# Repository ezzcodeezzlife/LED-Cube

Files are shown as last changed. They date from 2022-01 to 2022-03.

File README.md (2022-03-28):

# LED-Cube

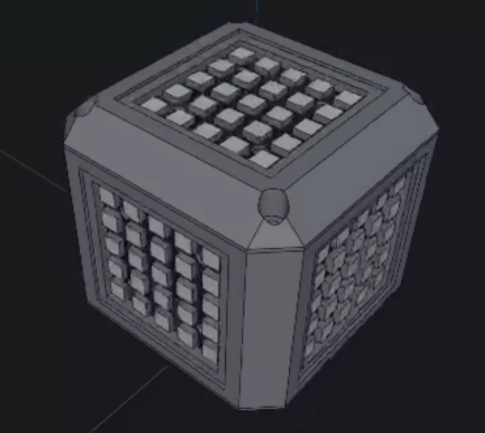
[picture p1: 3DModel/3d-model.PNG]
3d Cube


## Idee

Für unser Bachelorprojekt haben wir uns im Team überlegt, einen Würfel zu bauen, der auf jeder Seite LED Panels verbaut hat und somit Zahlen anzeigen kann. Beim Würfeln soll eine Lichtanimation und die gewürfelte Zahl aufleuchten. Die Zahl wird an einen Webserver übertragen und auf einer Website angezeigt. Mit zwei Würfeln kann man online mit seinen Freunden spielen.
Den Würfel möchten wir mit einem 3D-Druck selbst herstellen, der Controller befindet sich in dem Würfel und steuert die LEDs an.

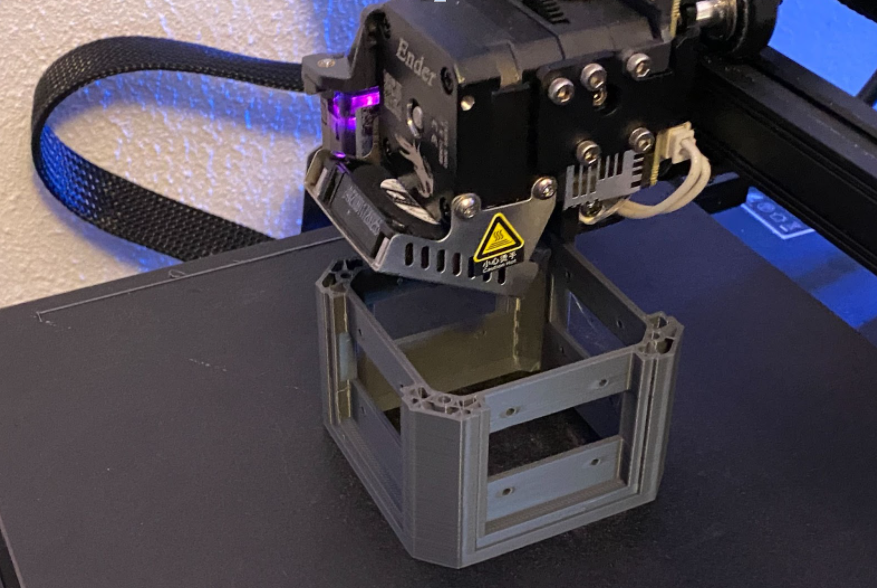
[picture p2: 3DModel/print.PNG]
3d Cube print


## Schaltplan
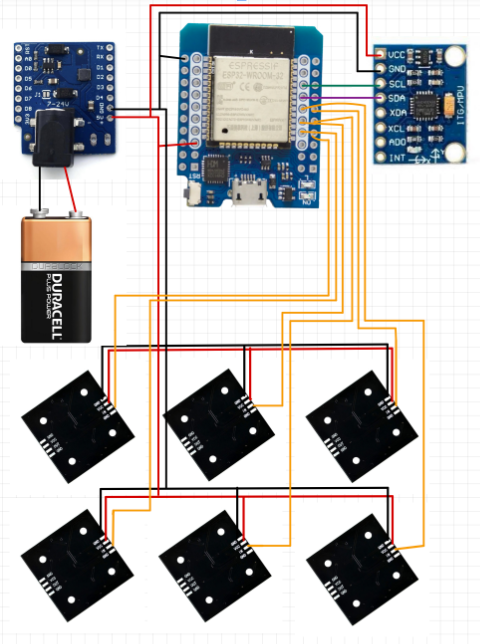
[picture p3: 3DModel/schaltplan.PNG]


## Dokumentation
[Ausarbeitung](https://github.com/ezzcodeezzlife/LED-Cube/blob/main/Dokumentation/Ausarbeitung_Projektvorstellung%20–%20LEDCube.pdf)

[Präsentation](https://github.com/ezzcodeezzlife/LED-Cube/blob/main/Dokumentation/Präsentation_Projektvorstellung%20–%20LEDCube.pdf)

[Video](https://github.com/ezzcodeezzlife/LED-Cube/blob/main/Dokumentation/LEDCube.mp4)

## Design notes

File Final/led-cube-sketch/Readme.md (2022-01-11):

# Arduino IDE konfigurieren

_Boardverwalter hinzufügen:_
* URL: https://dl.espressif.com/dl/package_esp32_index.json
* Paket: ESP32
* Board: WEMOS D1 MINI ESP32

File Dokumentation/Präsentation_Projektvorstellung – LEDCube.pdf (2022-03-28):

# LEDCube

# Bachelorprojekt DM

Marvin Spiegel, Ben Saloch, Fabian Stehle, Lara Ihlau

# Inhalte

- Idee
- Planung
- Durchführung
- Probleme
- Vorführung
- Ausblick

# IDEE

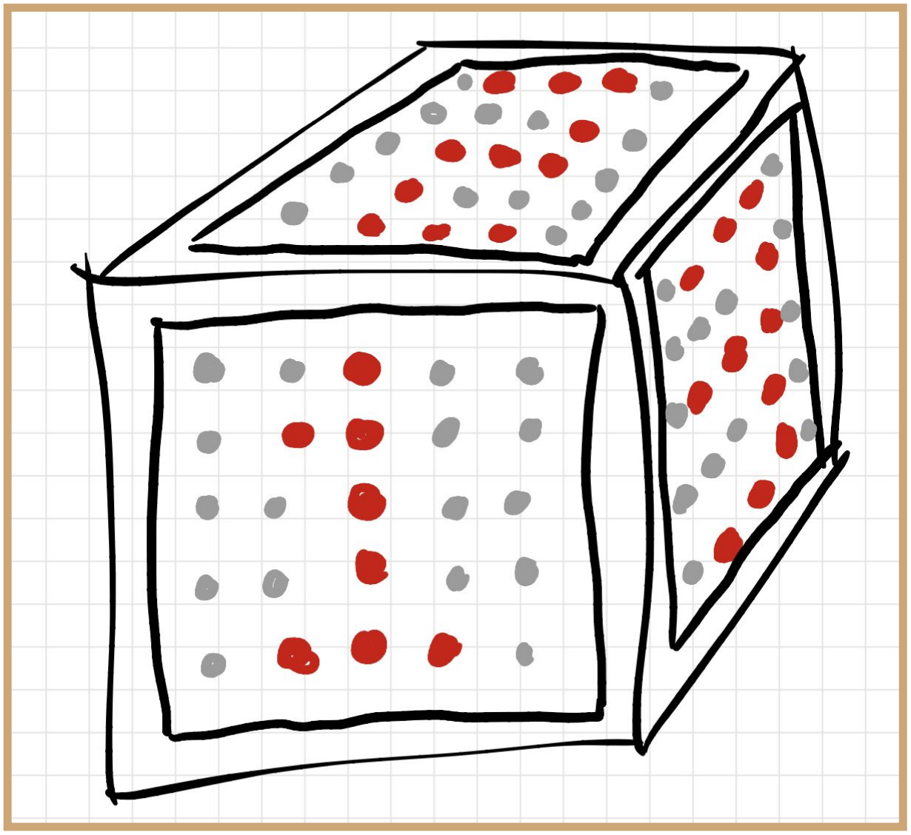
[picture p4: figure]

- Würfel mit Leuchten für Zahlen
- Anzeige über LED-Panels
- Sensor misst Lage im Raum
- Controller sendet an Webserver
- Anzeige einer Animation

# IDEE

# PLANUNG

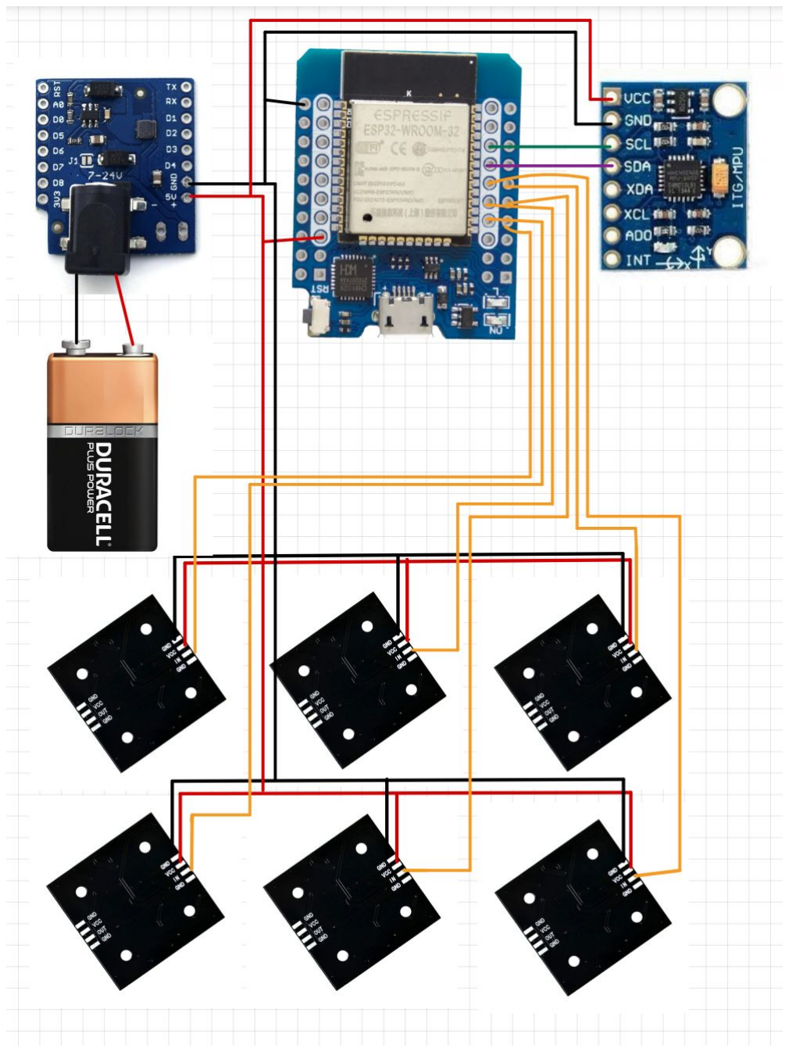
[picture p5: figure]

- zunächst andere Technik geplant

# PLANUNG

Controller | 1x Wemos D1 Mini ESP32
Input | 1x MPU 6050
Output | 6x WS2812 LED Matrix 5×5
Power | 1x 9V-Block-Batterie 1x battery-shield

Komponenten

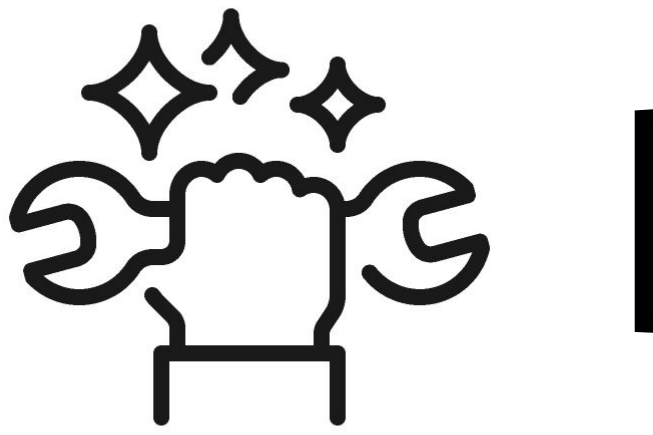
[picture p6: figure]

# DURCHFÜHRUNG

# DURCHFÜHRUNG 1/2

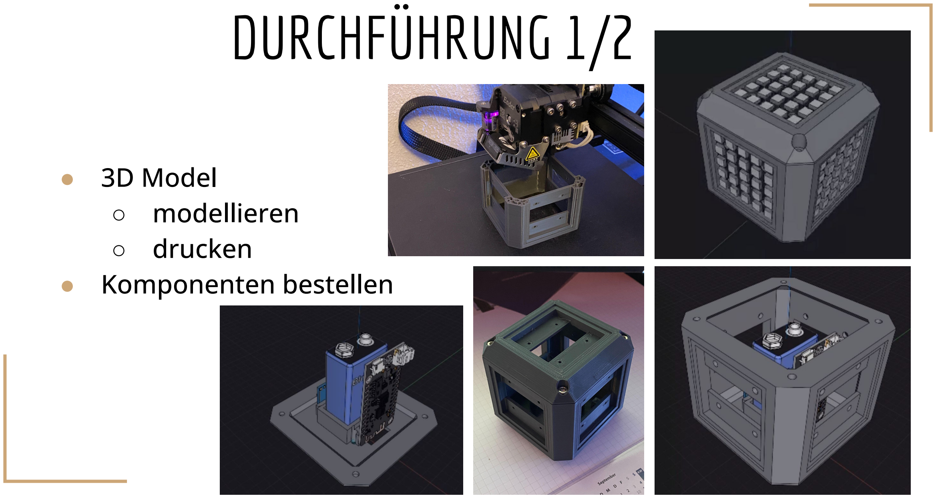
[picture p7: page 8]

- 3D Model
- modellieren
- drucken
- Komponenten bestellen

# DURCHFÜHRUNG 2/2

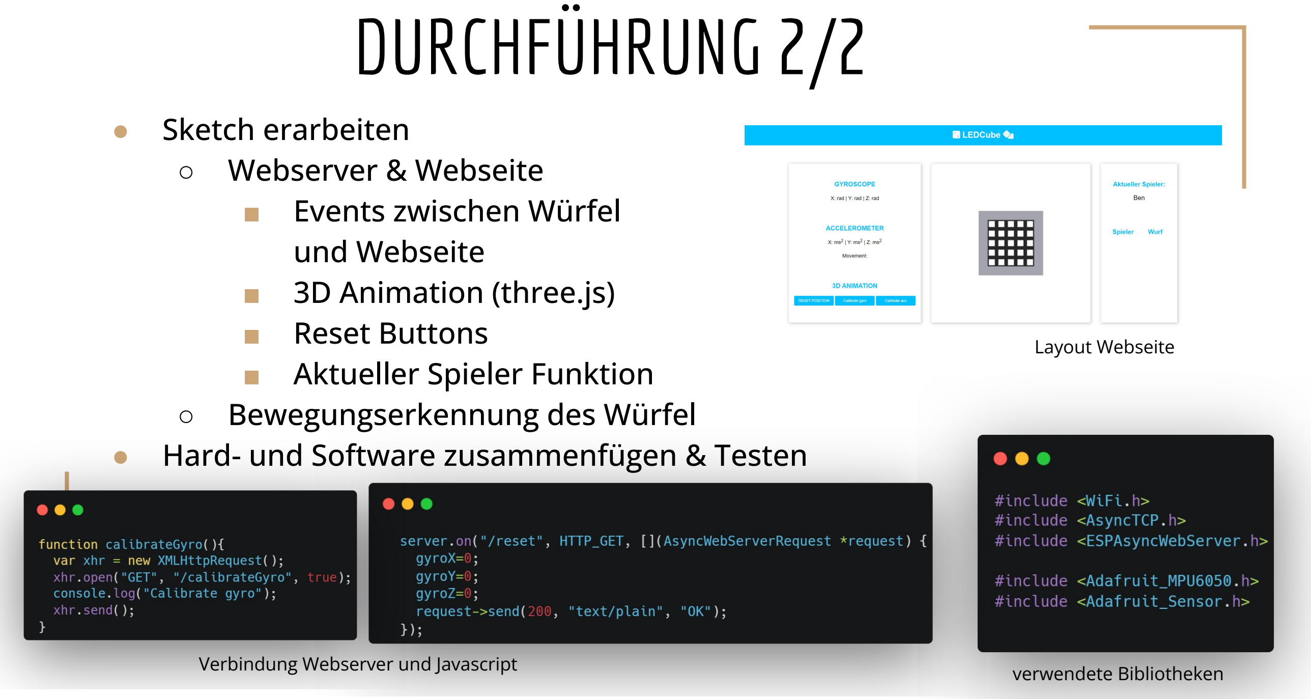
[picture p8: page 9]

- Sketch erarbeiten
- Webserver & Webseite
■ Events zwischen Würfel
und Webseite
■ 3D Animation (three.js)
■ Reset Buttons
■ Aktueller Spieler Funktion
- Bewegungserkennung des Würfel
- Hard- und Software zusammenfügen & Testen
Verbindung Webserver und Javascript | verwendete Bibliotheken

Layout Webseite

# AUFBAU

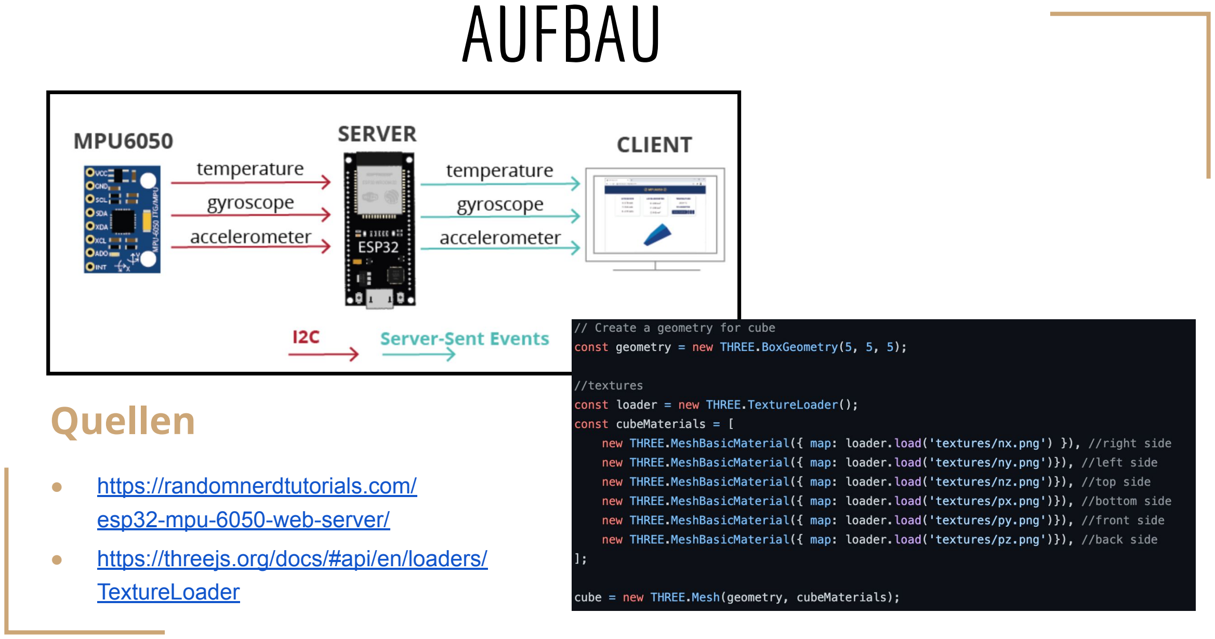
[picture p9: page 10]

Quellen

- https://randomnerdtutorials.com/esp32-mpu-6050-web-server/ (https://randomnerdtutorials.com/esp32-mpu-6050-web-server/)
- https://threejs.org/docs/#api/en/loaders/TextureLoader (https://threejs.org/docs/#api/en/loaders/TextureLoader)

# PROBLEME

# Probleme

- LEDs flackern
- LEDs verbrauchen zu viel Strom der 9V-Block-Batterie
- Threejs Würfel Texturen

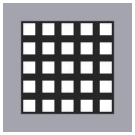
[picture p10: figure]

- Sketch ließ sich nicht hochladen
- keine Fehlermeldungen & Output

# VORFÜHRUNG

# AUSBLICK

# Vielen Dank für Ihre Aufmerksamkeit

weitere Fragen?

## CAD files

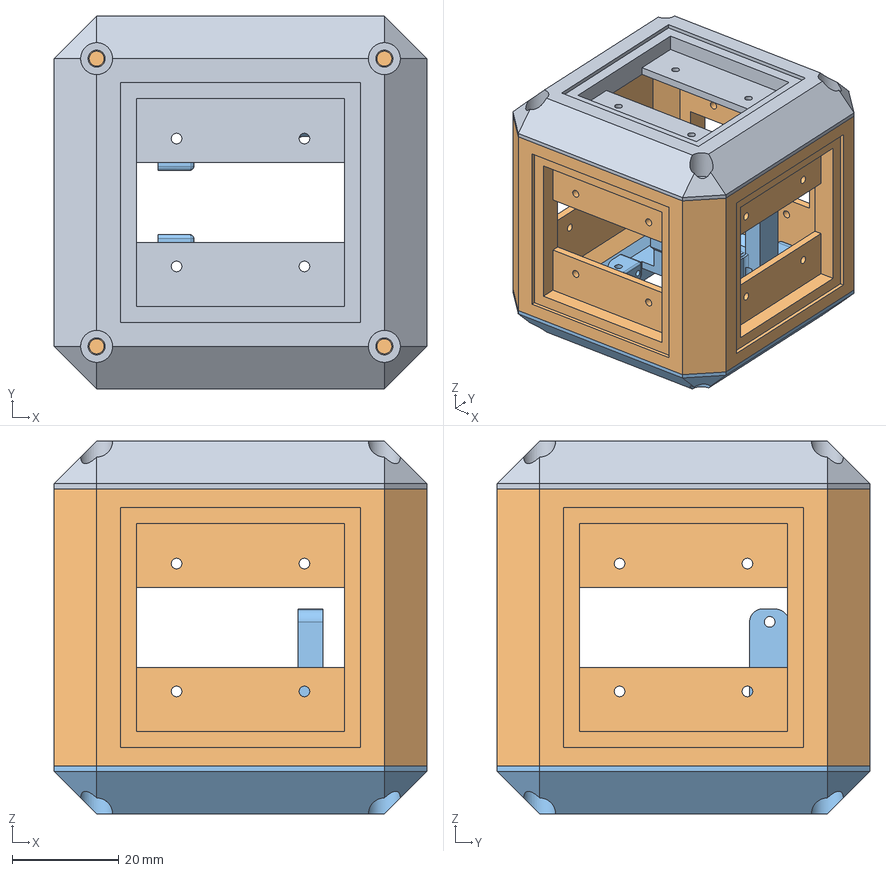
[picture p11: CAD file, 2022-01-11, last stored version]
3DModel/LEDCube.step
70.0 x 70.0 x 70.0 mm
top
middle
bottom

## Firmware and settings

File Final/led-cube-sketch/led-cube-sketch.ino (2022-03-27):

#include <Arduino.h>
#include <WiFi.h>
#include <AsyncTCP.h>
#include <ESPAsyncWebServer.h>
#include <Adafruit_MPU6050.h>
#include <Adafruit_Sensor.h>
#include <Arduino_JSON.h>
#include <Adafruit_GFX.h>
#include <Adafruit_NeoMatrix.h>
#include <Adafruit_NeoPixel.h>
#include "SPIFFS.h"

// Replace with your network credentials
const char* ssid = "LEDCube";
const char* password = "ledcube!";

// PINS
const int PIN1 = 18;
const int PIN2 = 19;
const int PIN3 = 23;
const int PIN4 = 33;
const int PIN5 = 5;
const int PIN6 = 26;
const int NUMPIXELS = 25;

// Create AsyncWebServer object on port 80
AsyncWebServer server(80);

// Create an Event Source on /events
AsyncEventSource events("/events");

// Json Variable to Hold Sensor Readings
JSONVar readings;

// Timer variables
unsigned long lastTime = 0;  
unsigned long lastTimeAcc = 0;
unsigned long movingStartTime = 0;
unsigned long movingStopTime = 0;
unsigned long gyroDelay = 10;
unsigned long accelerometerDelay = 200;
unsigned long movingStartDelay = 1000;
unsigned long movingStopDelay = 3000;

// MPU6050 object
Adafruit_MPU6050 mpu;
sensors_event_t a, g, temp;

/// Readings
float gyroX, gyroY, gyroZ;
float accX, accY, accZ;

// Gyroscope sensor deviation
float gyroXerror = -0.070218;
float gyroYerror = -0.011311;
float gyroZerror = -0.011546;

// Accelerometer deviation
float accXtarget = 0.0;
float accYtarget = 0.0;
float accZtarget = 9.81;
float accXerror = 0.273466;
float accYerror = 0.023643;
float accZerror = -1.416153;

// Calibration temp sums
float gyroXsum = 0;
float gyroYsum = 0;
float gyroZsum = 0;
float accXsum = 0;
float accYsum = 0;
float accZsum = 0;

// Movement detection states
boolean isMoving = false;
boolean wasMoving = false;

// LED panel control
Adafruit_NeoMatrix matrix1 = Adafruit_NeoMatrix(5, 5, PIN1,
  NEO_MATRIX_BOTTOM  + NEO_MATRIX_RIGHT +  //NEO_MATRIX_TOP     + NEO_MATRIX_LEFT +
  NEO_MATRIX_COLUMNS + NEO_MATRIX_ZIGZAG,
  NEO_GRB            + NEO_KHZ800);

Adafruit_NeoMatrix matrix2 = Adafruit_NeoMatrix(5, 5, PIN2,
  NEO_MATRIX_BOTTOM  + NEO_MATRIX_RIGHT +  //NEO_MATRIX_TOP     + NEO_MATRIX_LEFT +
  NEO_MATRIX_COLUMNS + NEO_MATRIX_ZIGZAG,
  NEO_GRB            + NEO_KHZ800);

Adafruit_NeoMatrix matrix3 = Adafruit_NeoMatrix(5, 5, PIN3,
  NEO_MATRIX_BOTTOM  + NEO_MATRIX_RIGHT +  //NEO_MATRIX_TOP     + NEO_MATRIX_LEFT +
  NEO_MATRIX_COLUMNS + NEO_MATRIX_ZIGZAG,
  NEO_GRB            + NEO_KHZ800);

Adafruit_NeoMatrix matrix4 = Adafruit_NeoMatrix(5, 5, PIN4,
  NEO_MATRIX_BOTTOM  + NEO_MATRIX_RIGHT +  //NEO_MATRIX_TOP     + NEO_MATRIX_LEFT +
  NEO_MATRIX_COLUMNS + NEO_MATRIX_ZIGZAG,
  NEO_GRB            + NEO_KHZ800);

Adafruit_NeoMatrix matrix5 = Adafruit_NeoMatrix(5, 5, PIN5,
  NEO_MATRIX_BOTTOM  + NEO_MATRIX_RIGHT +  //NEO_MATRIX_TOP     + NEO_MATRIX_LEFT +
  NEO_MATRIX_COLUMNS + NEO_MATRIX_ZIGZAG,
  NEO_GRB            + NEO_KHZ800);

Adafruit_NeoMatrix matrix6 = Adafruit_NeoMatrix(5, 5, PIN6,
  NEO_MATRIX_BOTTOM  + NEO_MATRIX_RIGHT +  //NEO_MATRIX_TOP     + NEO_MATRIX_LEFT +
  NEO_MATRIX_COLUMNS + NEO_MATRIX_ZIGZAG,
  NEO_GRB            + NEO_KHZ800);

struct RGB {
  byte r;
  byte g;
  byte b;
};

RGB w = { 255, 255, 255 }; //white
RGB r = { 255,   0,   0 }; //red
RGB t = { 0,   255,   0 }; //turkis
RGB b = { 0,     0, 255 }; //blue
RGB y = { 255, 255,   0 }; //yellow
RGB m = { 255,   0, 255 }; //magenta
RGB c = { 0,   255, 150 }; //cyan
RGB o = { 0,     0,   0 }; //off

RGB n1[5][5] = {
  {o, o, o, o, o},
  {o, o, o, o, o},
  {o, o, t, o, o},
  {o, o, o, o, o},
  {o, o, o, o, o},
};

RGB n2[5][5] = {
  {o, o, o, o, o},
  {o, y, o, o, o},
  {o, o, o, o, o},
  {o, o, o, y, o},
  {o, o, o, o, o},
};

RGB n3[5][5] = {
  {c, o, o, o, o},
  {o, o, o, o, o},
  {o, o, c, o, o},
  {o, o, o, o, o},
  {o, o, o, o, c},
};

RGB n4[5][5] = {
  {o, o, o, o, o},
  {o, b, o, b, o},
  {o, o, o, o, o},
  {o, b, o, b, o},
  {o, o, o, o, o},
};

RGB n5[5][5] = {
  {m, o, o, o, m},
  {o, o, o, o, o},
  {o, o, m, o, o},
  {o, o, o, o, o},
  {m, o, o, o, m},
};

RGB n6[5][5] = {
  {r, o, o, o, r},
  {o, o, o, o, o},
  {r, o, o, o, r},
  {o, o, o, o, o},
  {r, o, o, o, r},
};

RGB empty[5][5] = {
  {o, o, o, o, o},
  {o, o, o, o, o},
  {o, o, o, o, o},
  {o, o, o, o, o},
  {o, o, o, o, o},
};

// Init MPU6050
void initMPU(){
  if (!mpu.begin()) {
    Serial.println("Failed to find MPU6050 chip");
    while (1) {
      delay(10);
    }
  }
  Serial.println("MPU6050 Found!");
}

void initSPIFFS() {
  if (!SPIFFS.begin()) {
    Serial.println("An error has occurred while mounting SPIFFS");
  }
  Serial.println("SPIFFS mounted successfully");
}

// Initialize WiFi
void initWiFi() {
  WiFi.mode(WIFI_STA);
  WiFi.begin(ssid, password);
  Serial.println("");
  Serial.print("Connecting to WiFi...");
  while (WiFi.status() != WL_CONNECTED) {
    Serial.print(".");
    delay(1000);
  }
  Serial.println("");
  Serial.println(WiFi.localIP());
}

float getGyroXReading() {
  mpu.getEvent(&a, &g, &temp);
  
  float gyroX_temp = g.gyro.x;
  if(abs(gyroX_temp) > gyroXerror)  {
    gyroX += gyroX_temp/50.00;
  }
  
  return gyroX - gyroXerror;
}

float getGyroYReading() {
  mpu.getEvent(&a, &g, &temp);

  float gyroY_temp = g.gyro.y;
  if(abs(gyroY_temp) > gyroYerror) {
    gyroY += gyroY_temp/70.00;
  }
  
  return gyroY - gyroYerror;
}

float getGyroZReading() {
  mpu.getEvent(&a, &g, &temp);

  float gyroZ_temp = g.gyro.z;
  if(abs(gyroZ_temp) > gyroZerror) {
    gyroZ += gyroZ_temp/90.00;
  }
  
  return gyroZ - gyroZerror;
}

String getGyroReadings(){
  readings["gyroX"] = String(getGyroXReading());
  readings["gyroY"] = String(getGyroYReading());
  readings["gyroZ"] = String(getGyroZReading());

  String jsonString = JSON.stringify(readings);
  return jsonString;
}

float getAccXReading() {
  mpu.getEvent(&a, &g, &temp);
  return a.acceleration.x - accXerror;
}

float getAccYReading() {
  mpu.getEvent(&a, &g, &temp);
  return a.acceleration.y - accYerror;
}

float getAccZReading() {
  mpu.getEvent(&a, &g, &temp);
  return a.acceleration.z - accZerror;
}

String getAccReadingsJson() {
  readings["accX"] = String(getAccXReading());
  readings["accY"] = String(getAccYReading());
  readings["accZ"] = String(getAccZReading());
  String accString = JSON.stringify(readings);
  return accString;
}

void detectMovement() {
  float accX = getAccXReading();
  float accY = getAccYReading();
  float accZ = getAccZReading();
  
  boolean accDetected = false;
  if (abs(accX) > 15 || abs(accY) > 15 || abs(accZ) > 15) {
    accDetected = true;
  }
  
  if (accDetected) {
    if ((millis() - movingStartTime) > movingStartDelay) {
      movingStartTime = millis();
      movingStopTime = millis();
      if (!isMoving) {
        isMoving = true;
        Serial.printf("Started movement. ");
        Serial.printf("Acceleration: x=%f y=%f z=%f\n", accX, accY, accZ);  
      }
    }
  } else {
    if ((millis() - movingStopTime) > movingStopDelay) {
      movingStartTime = millis();
      movingStopTime = millis();
      if (isMoving) {
        isMoving = false;
        Serial.printf("Stopped movement. ");
        Serial.printf("Acceleration: x=%f y=%f z=%f\n", accX, accY, accZ); 
      }
    }
  }
}

void calibrateGyroscope(int precision) {
  Serial.printf("Doing %d gyro measurements\n", precision);
  
  for (int i = 0; i<precision; i++) {
    float gyroXreading = getGyroXReading();
    float gyroYreading = getGyroYReading();
    float gyroZreading = getGyroZReading();
    gyroXsum += gyroXreading;
    gyroYsum += gyroYreading;
    gyroZsum += gyroZreading;
  }

  gyroXerror = gyroXsum/precision;
  gyroYerror = gyroYsum/precision;
  gyroZerror = gyroZsum/precision;
  Serial.printf("Gyroscope average deviation: x=%f y=%f z=%f\n", gyroXerror, gyroYerror, gyroZerror);
}

void calibrateAccelerometer(int precision) {
  Serial.printf("Doing %d accelerometer measurements\n", precision);
  
  for (int i = 0; i<precision; i++) {
    float accXreading = getAccXReading();
    float accYreading = getAccYReading();
    float accZreading = getAccZReading();
    accXsum += accXreading;
    accYsum += accYreading;
    accZsum += accZreading;    
  }

  accXerror = accXsum/precision - accXtarget;
  accYerror = accYsum/precision - accYtarget;
  accZerror = accZsum/precision - accZtarget;
  Serial.printf("Accelerometer average deviation: x=%f y=%f z=%f\n", accXerror , accYerror, accZerror); 
}

void render(RGB frameArray[5][5]){
  for(int x = 0; x < 5; x++){
    for(int y = 0; y < 5; y++){
      uint32_t color = matrix1.Color(frameArray[x][y].r, frameArray[x][y].g, frameArray[x][y].b);
      matrix1.drawPixel(x, y, color);
      matrix2.drawPixel(x, y, color);
      matrix3.drawPixel(x, y, color);
      matrix4.drawPixel(x, y, color);
      matrix5.drawPixel(x, y, color);
      matrix6.drawPixel(x, y, color);
    }
  }
  matrix1.show();
  matrix2.show();
  matrix3.show();
  matrix4.show();
  matrix5.show();
  matrix6.show();
}

void setup() {
  Serial.begin(115200);
  initWiFi();
  initSPIFFS();
  initMPU();

  calibrateGyroscope(500);
  calibrateAccelerometer(500);

  // Handle Web Server
  server.on("/", HTTP_GET, [](AsyncWebServerRequest *request) {
    request->send(SPIFFS, "/index.html", "text/html");
  });

  server.serveStatic("/", SPIFFS, "/");

  server.on("/reset", HTTP_GET, [](AsyncWebServerRequest *request) {
    gyroX=0;
    gyroY=0;
    gyroZ=0;
    request->send(200, "text/plain", "OK");
  });

  server.on("/resetX", HTTP_GET, [](AsyncWebServerRequest *request) {
    gyroX=0;
    request->send(200, "text/plain", "OK");
  });

  server.on("/resetY", HTTP_GET, [](AsyncWebServerRequest *request) {
    gyroY=0;
    request->send(200, "text/plain", "OK");
  });

  server.on("/resetZ", HTTP_GET, [](AsyncWebServerRequest *request) {
    gyroZ=0;
    request->send(200, "text/plain", "OK");
  });

  server.on("/calibrateGyro", HTTP_GET, [](AsyncWebServerRequest *request) {
    request->send(200, "text/plain", "OK");
    calibrateGyroscope(500);
  });

  server.on("/calibrateAcc", HTTP_GET, [](AsyncWebServerRequest *request) {
    request->send(200, "text/plain", "OK");
    calibrateAccelerometer(500);
  });

  // Handle Web Server Events
  events.onConnect([](AsyncEventSourceClient *client) {
    if(client->lastId()){
      Serial.printf("Client reconnected! Last message ID that it got is: %u\n", client->lastId());
    }
    // send event with message "hello!", id current millis
    // and set reconnect delay to 1 second
    client->send("hello!", NULL, millis(), 10000);
  });
  server.addHandler(&events);

  server.begin();

  matrix1.begin();
  matrix1.setBrightness(10);
  matrix2.begin();
  matrix2.setBrightness(10);
  matrix3.begin();
  matrix3.setBrightness(10);
  matrix4.begin();
  matrix4.setBrightness(10);
  matrix5.begin();
  matrix5.setBrightness(10);
  matrix6.begin();
  matrix6.setBrightness(10);
}

void loop() {
  
  if ((millis() - lastTime) > gyroDelay) {
    // Send Events to the Web Server with the Sensor Readings
    events.send(getGyroReadings().c_str(),"gyro_readings", millis());
    lastTime = millis();
  }
  if ((millis() - lastTimeAcc) > accelerometerDelay) {
    // Send Events to the Web Server with the Sensor Readings
    events.send(getAccReadingsJson().c_str(),"accelerometer_readings", millis());
    lastTimeAcc = millis();

    detectMovement();
    if (wasMoving != isMoving) {
      wasMoving = isMoving;
      events.send(String(isMoving).c_str(),"accelerometer_movement", millis());

      if (isMoving) {
        render(empty);
      } else {
        // reset gyro
        gyroX=0;
        gyroY=0;
        gyroZ=0;
        
        // roll the dice
        int randomNumber = random(6) + 1;
        Serial.printf("Random number: %d \n", randomNumber);
        events.send(String(randomNumber).c_str(),"dice_result", millis());

        // show numbers
        switch(randomNumber) {
          case 1:
            render(n1);
            break;
          case 2:
            render(n2);
            break;
          case 3:
            render(n3);
            break;
          case 4:
            render(n4);
            break;
          case 5:
            render(n5);
            break;
          case 6:
            render(n6);
            break;
        }
      }
    }
  }
}

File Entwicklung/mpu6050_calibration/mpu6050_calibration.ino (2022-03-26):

#include <Arduino.h>
#include <Adafruit_MPU6050.h>
#include <Adafruit_Sensor.h>

// Create a sensor object
Adafruit_MPU6050 mpu;
sensors_event_t a, g, temp;

float gyroX, gyroY, gyroZ;
float accX, accY, accZ;

int ATTEMPTS = 200;

// Gyroscope deviation
float gyroXerror = -0.070218;
float gyroYerror = -0.011311;
float gyroZerror = -0.011546;

// Acceleration deviation
float accXtarget = 0.0;
float accYtarget = 0.0;
float accZtarget = 9.81;
float accXerror = 0.273466;
float accYerror = 0.023643;
float accZerror = -1.416153;

// Sums
float gyroXsum = 0;
float gyroYsum = 0;
float gyroZsum = 0;
float accXsum = 0;
float accYsum = 0;
float accZsum = 0;

// Counter
int gyroReadCounter = 0;
int accReadCounter = 0;

// Init MPU6050
void initMPU(){
  if (!mpu.begin()) {
    Serial.println("Failed to find MPU6050 chip");
    while (1) {
      delay(10);
    }
  }
  Serial.println("MPU6050 Found!");
}

float getGyroXReading() {
  mpu.getEvent(&a, &g, &temp);
  
  float gyroX_temp = g.gyro.x;
  if(abs(gyroX_temp) > gyroXerror)  {
    gyroX += gyroX_temp/50.00;
  }
  
  return gyroX - gyroXerror;
}

float getGyroYReading() {
  mpu.getEvent(&a, &g, &temp);

  float gyroY_temp = g.gyro.y;
  if(abs(gyroY_temp) > gyroYerror) {
    gyroY += gyroY_temp/70.00;
  }
  
  return gyroY - gyroYerror;
}

float getGyroZReading() {
  mpu.getEvent(&a, &g, &temp);

  float gyroZ_temp = g.gyro.z;
  if(abs(gyroZ_temp) > gyroZerror) {
    gyroZ += gyroZ_temp/90.00;
  }
  
  return gyroZ - gyroZerror;
}

float getAccXReading() {
  mpu.getEvent(&a, &g, &temp);
  return a.acceleration.x - accXerror;
}

float getAccYReading() {
  mpu.getEvent(&a, &g, &temp);
  return a.acceleration.y - accYerror;
}

float getAccZReading() {
  mpu.getEvent(&a, &g, &temp);
  return a.acceleration.z - accZerror;
}



void setup() {
  Serial.begin(115200);
  initMPU();
}

void loop() {
  float gyroXreading = getGyroXReading();
  float gyroYreading = getGyroYReading();
  float gyroZreading = getGyroZReading();

  if (gyroReadCounter <= ATTEMPTS) {
    if (gyroReadCounter == 0) {
      Serial.printf("Doing %d gyro measurements\n", ATTEMPTS);
    }
    gyroXsum += gyroXreading;
    gyroYsum += gyroYreading;
    gyroZsum += gyroZreading;

    if (gyroReadCounter == ATTEMPTS) {
      float gyroXaverage = gyroXsum/ATTEMPTS;
      float gyroYaverage = gyroYsum/ATTEMPTS;
      float gyroZaverage = gyroZsum/ATTEMPTS;
      Serial.printf("Gyro average: x=%f y=%f z=%f\n", gyroXaverage, gyroYaverage, gyroZaverage); 
      Serial.printf("Gyro deviation: x=%f y=%f z=%f\n", gyroXaverage - 0, gyroYaverage - 0, gyroZaverage - 0); 
    }
    gyroReadCounter++;
  } 
  
  float accXreading = getAccXReading();
  float accYreading = getAccYReading();
  float accZreading = getAccZReading();

  if (accReadCounter <= ATTEMPTS) {
    if (accReadCounter == 0) {
      Serial.printf("Doing %d acc measurements\n", ATTEMPTS);
    }
    accXsum += accXreading;
    accYsum += accYreading;
    accZsum += accZreading;

    if (accReadCounter == ATTEMPTS) {
      float accXaverage = accXsum/ATTEMPTS;
      float accYaverage = accYsum/ATTEMPTS;
      float accZaverage = accZsum/ATTEMPTS;
      Serial.printf("Acceleration average: x=%f y=%f z=%f\n", accXaverage, accYaverage, accZaverage); 
      Serial.printf("Acceleration deviation: x=%f y=%f z=%f\n", accXaverage - accXtarget, accYaverage - accYtarget, accZaverage - accZtarget); 
    }
    accReadCounter++;
  }
}

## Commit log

2022-01-11 Add files via upload
    V1.0
    [LEDCube.step]
2022-01-11 Add files via upload (#1)
    [LEDCube.step]
2022-01-11 Move arduino sketch to seperate folder
2022-01-11 Update arduino ide documentation
2022-02-08 Add files via upload
    Test Sketch für LED Martrizen
2022-02-14 Include calibration algorithm into main sketch
2022-02-20 Add calibration buttons to webapp
    * Initial calibration moved to setup() function
    * Implement endpoint in sketch
    * Implement http call in js
    * Show buttons in html
2022-02-20 Removed unnecessary parameter
    * Remove "this" parameter from calibrateGyro() and calibrateAcc() calls
